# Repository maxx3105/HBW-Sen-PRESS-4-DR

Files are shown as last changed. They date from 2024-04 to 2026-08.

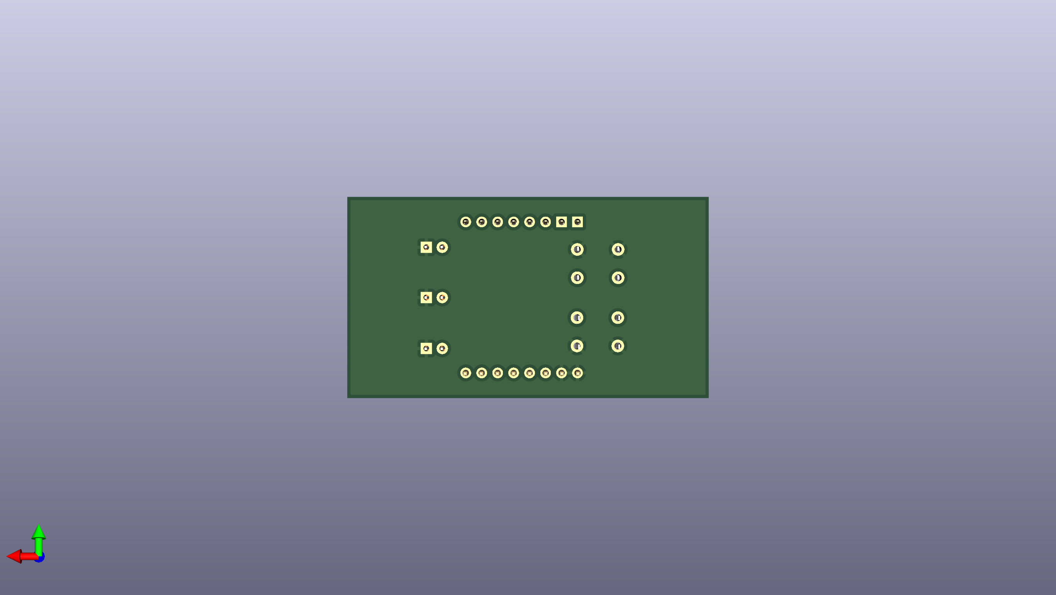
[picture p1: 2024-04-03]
HBW-Sen-PRESS-4_Platine2/Pictures/HBW-Sen-PRESS-4_Platine2_BOTTOM.png

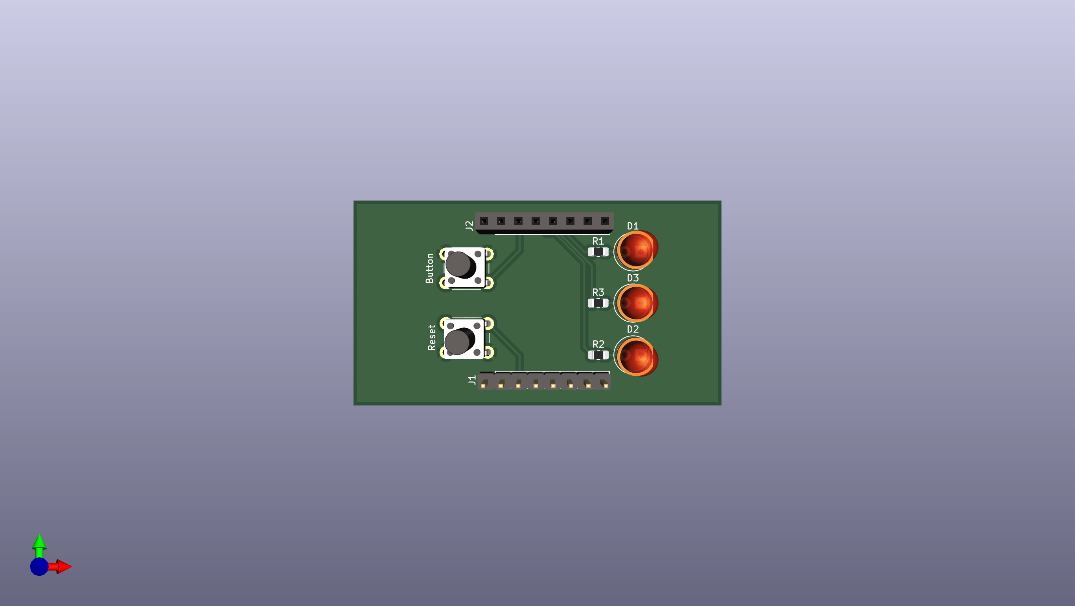
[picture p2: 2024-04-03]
HBW-Sen-PRESS-4_Platine2/Pictures/HBW-Sen-PRESS-4_Platine2_TOP.png

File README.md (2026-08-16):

# HBW-Sen-PRESS-4-DR

HomeMatic-Wired-Drucksensormodul für Hutschienenmontage

## Überblick

HomeMatic-Wired-Gerät (RS485) zur Überwachung hydraulischer Drücke mit
Industrie-Drucksensoren. Es stellt 4 analoge Sensoreingänge bereit (A0–A3).
Nicht belegte Kanäle werden in der CCU über `Sensortyp = NICHT_BELEGT` abgeschaltet.

### Basiert auf:
- **HBWired** von Thorsten Pferdekaemper: https://github.com/ThorstenPferdekaemper/HBWired
- **HB-UNI-Sen-PRESS** von jp112sdl: https://github.com/jp112sdl/HB-UNI-Sen-PRESS

## Aufbau des Repositories

```
HBW-Sen-PRESS-4-DR/
├── HBW-Sen-PRESS-4-DR/            Arduino-Sketch (Ordnername muss zur .ino passen)
│   ├── HBW-Sen-PRESS-4-DR.ino
│   ├── HBW-Sen-PRESS-4-DR_config_example.h   Pins, EepromPtr, USE_HARDWARE_SERIAL
│   ├── HBWAnalogPRESS.h
│   └── HBWAnalogPRESS.cpp
├── hbw-sen-press-4-dr.xml         CCU-Gerätedefinition (hs485types)
├── HBW-Sen-PRESS-4_Platine1/    KiCad-Projekt Hauptplatine (+ Gerber)
├── HBW-Sen-PRESS-4_Platine2/    KiCad-Projekt zweite Platine (+ Gerber)
├── BUGFIXES.md                  was in v0.01–v0.03 defekt war und warum
└── CLAUDE.md                    kompakter Projektstand / Übergabenotizen
```

## Hardware

### Unterstützte Sensoren
- **0,5 MPa** Hydraulik-Drucksensor (0–5 bar / 0–72,5 PSI)
- **1,2 MPa** Hydraulik-Drucksensor (0–12 bar / 0–174 PSI)

Beide liefern ein Analogsignal von **0,5 V bis 4,5 V**:
- 0,5 V = 0 bar
- 4,5 V = Endwert (5 bzw. 12 bar je nach Sensortyp)

### Bauteile
- **ATmega328P** Mikrocontroller (alternativ Arduino Nano)
- **MAX487E** RS485-Transceiver
- **MC34063AD** Step-Down-Wandler (24 V Bus → 5 V)
- Analogeingänge: A0–A3 in Verwendung

### Merkmale der Platine
- Hutschienenmontage
- Identify-LED zum Auffinden im Verteiler (blinkt, solange `IDENTIFY_LED` in
  den Geräteparametern gesetzt ist)
- RS485-Busanschluss (A, B, GND, +24 V)
- Schraubklemmen für die Sensoren
- ISP-Programmierstecker
- Status-LED
- Taster für Werksreset

## Pinbelegung

| Pin | Funktion |
|-----|---|
| A0–A3 | Analogeingänge der Drucksensoren |
| D3 | RS485 TXEN |
| A6 | Taster für Werksreset |
| D12 | Identify-LED (optional, auskommentieren wenn nicht bestückt) |
| D13 | Status-LED |

Pins, `EepromPtr` und `USE_HARDWARE_SERIAL` stehen in
`HBW-Sen-PRESS-4-DR_config_example.h`. Bei abweichender Hardware die Datei
kopieren und die Kopie im Sketch einbinden — dann überschreibt sie eine neue
Version aus GitHub nicht.

## Funktionsumfang

### Konfiguration je Kanal (in CCU/FHEM)

| Parameter | Bereich | Vorgabe | Bedeutung |
|---|---|---|---|
| **Sensortyp** | 0.5MPa / 1.2MPa / NICHT_BELEGT | NICHT_BELEGT | Sensortyp wählen oder Kanal abschalten |
| **SEND_DELTA_VALUE** | 0,0–2,54 bar | 0,1 bar | Sendet, sobald sich der Druck um diesen Betrag ändert |
| **OFFSET** | −1,27 bis +1,27 bar | 0,0 bar | Kalibrier-Offset (vorzeichenbehaftet, mit Bias 127 gespeichert) |
| **UPDATE_INTERVAL** | 1–254 s | 30 s | Pause zwischen zwei Messreihen |
| **SEND_MIN_INTERVAL** | 10–3600 s | 30 s | Mindestabstand zwischen zwei Sendungen |
| **SEND_MAX_INTERVAL** | 10–3600 s | 600 s | Spätestens nach dieser Zeit wird gesendet |

Die Obergrenzen vermeiden den Wert aus lauter Einsen (`0xFF` / `0xFFFF`) — der
markiert eine gelöschte EEPROM-Zelle und wird stattdessen auf die Vorgabe
abgebildet.

### Ablauf

1. **Messung**: alle SAMPLE_INTERVAL (3 s) ein ADC-Wert, gemittelt über
   MAX_SAMPLES (4) — ohne blockierendes `delay()`, damit der RS485-Empfang
   reaktionsfähig bleibt. Nach einer vollständigen Messreihe pausiert der Kanal
   für UPDATE_INTERVAL.
2. **Umrechnung**: ADC → Spannung → Druck (abhängig vom Sensortyp)
3. **Kalibrierung**: OFFSET anwenden
4. **Sendeentscheidung** (in jedem Schleifendurchlauf geprüft, unabhängig vom
   Messzyklus):
   - Mindestens SEND_MIN_INTERVAL seit der letzten Sendung abwarten
   - Senden, wenn sich der Druck um ≥ SEND_DELTA_VALUE geändert hat
   - Nach SEND_MAX_INTERVAL in jedem Fall senden
   - Bei `BUS_BUSY` bleibt der Messwert offen, statt als gesendet zu gelten

Ein vollständiger Messwert entsteht damit alle
`(MAX_SAMPLES − 1) × SAMPLE_INTERVAL + UPDATE_INTERVAL` Sekunden, mit den
Vorgabewerten also alle 39 s. `UPDATE_INTERVAL` ist die Pause *zwischen* den
Messreihen, nicht die Messrate — auf 1 s gestellt misst das Gerät alle 10 s.

## Installation

### 1. Arduino-IDE vorbereiten
```bash
git clone https://github.com/ThorstenPferdekaemper/HBWired
# nach Arduino/libraries/HBWired kopieren
```

### 2. Übersetzen und flashen

Der Sketch liegt im Unterordner `HBW-Sen-PRESS-4-DR/` (der Ordnername muss dem
`.ino`-Namen entsprechen).

- `HBW-Sen-PRESS-4-DR/HBW-Sen-PRESS-4-DR.ino` in der Arduino-IDE öffnen
- Board: **Arduino Nano** (ATmega328P)
- Betriebsart im Konfig-Header wählen: `USE_HARDWARE_SERIAL` gesetzt =
  Produktivbetrieb (RS485 über die Hardware-UART, keine Debug-Ausgabe),
  auskommentiert = Debug über USB und RS485 über SoftwareSerial
- Flashen über ISP oder Bootloader

Oder aus dem Projektverzeichnis heraus:

```
arduino-cli compile --fqbn arduino:avr:nano:cpu=atmega328 HBW-Sen-PRESS-4-DR
arduino-cli compile --fqbn arduino:avr:nano:cpu=atmega328 --upload --programmer usbasp HBW-Sen-PRESS-4-DR
```

Hinweis: Ist die EESAVE-Fuse nicht gesetzt, löscht jeder ISP-Flash das EEPROM —
und damit die Busadresse.

### 3. CCU/RaspberryMatic einrichten
1. `hbw-sen-press-4-dr.xml` auf die CCU kopieren
2. Gerätedefinition einbinden (Addon bzw. FHEM)
3. Gerät an den RS485-Bus anschließen
4. Anlernen und aus dem Posteingang übernehmen

## EEPROM-Belegung

`HBWDevice` liest die Konfigurationsstruktur ab EEPROM-Adresse `0x01`
(siehe `readConfig()` in HBWired.cpp), Struktur-Offset 6 landet also auf `0x07`.

```
0x00      : Gerätetyp (0x50)
0x01      : Logging-Zeit
0x02-0x05 : Zentralen-Adresse
0x06      : Bit 0 Direct-Link-Flag, Bit 1 Identify-LED (invertiert: 1 = aus)
0x07      : Kanal 1, Konfiguration (8 Byte)
  +0: send_delta_value
  +1: offset (Bias 127: 0 = −1,27 bar, 127 = 0,00 bar, 254 = +1,27 bar)
  +2-3: send_max_interval (16 Bit, little endian)
  +4-5: send_min_interval (16 Bit, little endian)
  +6: update_interval
  +7: pressure_sensor_type
0x0F/0x17/0x1F : Kanal 2..4, Konfiguration
0x3FC-0x3FF : OWN_ADDRESS (Busadresse, E2END−3 beim 1-kB-EEPROM des 328P)
```

Die Belegung ist über drei `static_assert` in
`HBW-Sen-PRESS-4-DR/HBW-Sen-PRESS-4-DR.ino` an die XML gekoppelt — Strukturgröße,
Startoffset der Kanäle und der Abstand zu `OWN_ADDRESS` müssen passen,
sonst bricht der Build.

## Fehlersuche

### Keine Messwerte / alles null
- Verdrahtung prüfen (3-adrig: VCC, GND, Signal)
- Liefert der Sensor tatsächlich 0,5–4,5 V?
- Ist der Kanal freigegeben (`Sensortyp` ≠ `NICHT_BELEGT`)? Bei abgeschaltetem
  Kanal wird weder gemessen noch gesendet.

### Falsche Druckwerte
- Richtigen Sensortyp gewählt (0,5 MPa vs. 1,2 MPa)?
- Zur Kalibrierung den Parameter OFFSET verwenden
- VCC muss *nicht* exakt 5,0 V betragen: Die Sensoren arbeiten ratiometrisch,
  ihr Ausgang skaliert mit der Versorgung. Hängen Sensor und ADC an derselben
  5-V-Schiene, hebt sich die Abweichung des Reglers auf — deshalb wird die
  VCC-Referenz des ADC benutzt und nicht die interne 1,1-V-Referenz.
  Wichtig ist nur, dass Sensor und MCU aus **derselben** Schiene versorgt werden.

### Gerät kommuniziert nicht
- RS485-Verdrahtung prüfen (A/B nicht vertauscht)
- TX/RX-Aktivität beobachten

## Lizenz

Creative Commons BY-NC-SA 3.0 AT
http://creativecommons.org/licenses/by-nc-sa/3.0/at/

## Dank an

- Thorsten Pferdekaemper – HBWired-Framework
- Dirk Hoffmann – Beiträge zu HBWired
- jp112sdl – ursprüngliches Konzept HB-UNI-Sen-PRESS

## Änderungsverlauf

### v0.05
- Gerät in HBW-Sen-PRESS-4-DR umbenannt (Typ-Byte bleibt 0x50; wegen des
  Namenswechsels in der CCU löschen und neu anlernen)
- Pinbelegung, `EepromPtr` und `USE_HARDWARE_SERIAL` in einen Konfig-Header
  ausgelagert
- Identify-LED ergänzt

### v0.04
- Kanalzahl auf 4 festgelegt (A0–A3)

### v0.01 (02.04.2024)
- Erste Fassung auf Basis von HB-UNI-Sen-PRESS
- CCU-Anbindung über XML

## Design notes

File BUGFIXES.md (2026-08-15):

# Bug Fixes und Verbesserungen - HBW-Sen-PRESS-4-DR

## v0.03 → v0.04: Kanalzahl 4, count_from_sysinfo endgültig ausgeschlossen

Das CRMB2-Gehäuse führt nur 4 Sensoranschlüsse heraus, also `NUMBER_OF_CHAN 4`
und `count="4"`. Zuvor wurde geprüft, ob sich die Kanalzahl dynamisch über
`count_from_sysinfo` melden lässt (eine XML/Firmware für 4 und 8 Kanäle).

**Ergebnis: geht nicht.** Belegt auf zwei Wegen:

1. **Binär**, auf der OpenCCU:
```
strings $(which rfd)     | grep -i "count_from\|sysinfo"
   -> SYSINFO, SYSINFO_SWVER, SYSINFO_TYPE, SYSINFO_SERIAL, SYSINFO_CODE,
      SYSINFO_CH_A, SYSINFO_CH_B, count_from_sysinfo, peering_sysinfo_expect_channel

strings $(which hs485d)  | grep -i "count_from\|count.*channel\|channel.*count"
   -> (keine Treffer)
```
`hs485d` kennt zwar `sysinfo` (gemeinsamer Matching-Code mit `rfd`, Meldung
`Matching "sysinfo" attribute … Trying "type" instead`), aber weder
`count_from_sysinfo` noch irgendeinen anders benannten Ersatz. Bei Funk sitzt
die Kanalzahl in der Pairing-Sysinfo (`SYSINFO_CH_A`/`_CH_B`, Byte 23) — das
Wired-Protokoll überträgt so etwas nicht.

2. **Am Bus:** Mit `count_from_sysinfo="23.0:0.4"` statt `count` erkennt die CCU
das Gerät weiterhin korrekt (Typenbezeichnung `HBW-Sen-PRESS`, Firmware 0.03,
Geräteparameter vorhanden), legt aber **null Kanäle** an → „Keine Parameter
einstellbar". Das unbekannte Attribut wird ignoriert, und ohne `count` gibt es
keine Kanäle.

Variable Kanalzahl geht bei Wired deshalb nur über getrennte Gerätetypen mit
eigenem Typ-Byte — so wie eq3 (`hmw_io_4_fm` 0x10 / `hmw_io_12_fm` 0x1B) und
wie im eigenen Bestand `hbw_lc_rgbww_3.xml` (0xD2) / `hbw_lc_rgbww_6.xml` (0xD1).

Merksatz für künftige Fälle: Ob ein CCU-Daemon ein XML-Attribut auswertet, klärt
`strings` auf das Binary — schneller und risikofreier als XML-Tausch am
laufenden System. Dass ein Attribut in keiner XML vorkommt, ist nur ein Indiz.

---

## Übersicht der Änderungen von v0.02 → v0.03

Gemeinsame Ursache der XML-Fehler: Die Datei wurde aus der Funk-XML von
HB-UNI-Sen-PRESS abgeleitet, nicht aus einer Wired-XML. HB (Funk/CC1101) und
HBW (Wired/RS485) haben unterschiedliche Frame-Layouts und Parameter-Interfaces.

Referenzen für den korrigierten Stand:
- `hs485types/hmw_sen_sc_12_dr.xml` (eq3-Original)
- `JP-HB-Devices-addon-fork/.../hs485types/hbw_1w_t10_v1.xml` (loetmeister,
  HBWired-Sensormodul mit analogen Messwerten — direkte Vorlage)
- `HBWired/src/HBWAnalogIn.cpp` (Lib-Referenz für Sampling und Sendelogik)

---

### 🔴 BLOCKER 1: Event-Frame in Funk-Syntax

**Problem:**
```xml
<frame id="PRESSURE_EVENT" direction="from_device" event="true"
       type="0x53" channel_field="11">
    <parameter type="integer" index="12.0" size="2.0" param="UNI_PRESSURE"/>
</frame>
```

`0x53` ist der MEASURE_EVENT-Typ eines AskSin-Funkgeräts. HBWired sendet aber:

```cpp
// HBWired.cpp, sendInfoMessage()
txFrame.data[0] = 0x69;         // 'i'
txFrame.data[1] = channel;      // Sensornummer
memcpy(&(txFrame.data[2]), data, length);
```

HMW-Frame-Layout: 4 Byte Ziel + 1 Byte Control + 4 Byte Absender = Index 0..8,
danach Kommando @9, Kanal @10, Payload ab @11.

**Auswirkung:** Die CCU ordnet die Info-Nachrichten keinem Datenpunkt zu. Der
Messwert wäre nie angekommen — auch bei fehlerfreiem Bus und Pairing.

**Fix:** ✅
```xml
<frame id="INFO_LEVEL" direction="from_device" event="true"
       type="#i" channel_field="10">
    <parameter type="integer" index="11.0" size="2.0" param="UNI_PRESSURE"/>
</frame>
```

---

### 🔴 BLOCKER 2: Sensortyp über `interface="config"`

**Problem:**
```xml
<physical type="integer" interface="config" list="1" index="+7.0" size="1"/>
```

`interface="config"` mit `list=` ist AskSin-Funk. HM485/hs485d kennt keine
Lists — der Parameter wird nie ins EEPROM geschrieben.

**Auswirkung:** `pressure_sensor_type` bleibt 0xFF → `afterReadConfig()` setzt
auf 0 → **jeder Kanal dauerhaft deaktiviert**, unabhängig von der CCU-Auswahl.

**Fix:** ✅
```xml
<physical size="1.0" type="integer" interface="eeprom">
    <address index="+7.0"/>
</physical>
```

---

### 🟠 BLOCKER 3: `count_from_sysinfo` existiert im Wired-Zweig nicht

**Problem:** `count_from_sysinfo="23.0:0.3"` kommt in keiner der 15 eq3- und
21 loetmeister-Wired-XMLs vor — nur in rftypes (Funk). Zusätzlich fassen die
3 Bit nur Werte 0..7, die angestrebten 8 Kanäle passen gar nicht hinein.

**Fix:** ✅ Festes `count="8"`. Damit entfallen das Kanalzahl-Byte an 0x17, die
`EEPROM.write(0x17, ...)` im Sketch und beide Padding-Blöcke; die Kanalconfigs
rücken von 0x23 auf 0x07 (direkt hinter den Device-Master-Block, wie in der
Referenz-XML).

---

### 🟠 Fehlend: LEVEL_GET und OWN_ADDRESS

- Ohne `<frame id="LEVEL_GET" direction="to_device" type="#S" channel_field="10"/>`
  und `<get request="LEVEL_GET" response="INFO_LEVEL"/>` kann die CCU den Wert
  nicht aktiv abfragen. HBWired beantwortet 'S' bereits (`HBWired.cpp`, `case 'S'`).
- `OWN_ADDRESS` fehlte komplett. Ergänzt an `0x03FC` — beim ATmega328P ist
  E2END = 0x3FF, die Busadresse liegt in den letzten 4 EEPROM-Bytes.
  Ohne diesen Block lässt sich die Busadresse nicht über die CCU setzen.

---

### 🔴 CODE: blockierendes `delay()` im ADC-Sampling

**Problem:** In v0.02 als „Verbesserung" eingeführt (siehe Punkt 8 weiter unten):
```cpp
for(uint8_t i = 0; i < 4; i++) {
    adcSum += analogRead(pin);
    delay(2);
}
```

**Auswirkung:** 8 ms blockierte `loop()` pro Messung und Kanal. Bei
SoftwareSerial-RS485 (Debug-Modus, ATmega328P hat nur einen UART) gehen in
dieser Zeit Empfangs-Frames verloren. `analogRead()` selbst braucht ~112 µs und
ist bereits die Wandlungspause — das `delay(2)` bringt keinen Rauschgewinn.

**Fix:** ✅ Inkrementelles Sampling wie `HBWAnalogIn`: ein Sample pro
`loop()`-Durchlauf, Mittelwert nach `MAX_SAMPLES`. Anders als in der Lib sind
`sum`/`sampleCount` **Member statt `static`** — in `HBWAnalogIn.cpp` sind sie
`static` in einer Member-Funktion und damit über alle Kanäle geteilt, was bei
mehreren Instanzen die Samples vermischt.

---

### 🟠 CODE: Sendeergebnis wurde ignoriert

**Problem:**
```cpp
device->sendInfoMessage(channel, 2, data);
lastSendValue = currentValue;   // auch wenn der Bus belegt war
```

**Auswirkung:** Bei `BUS_BUSY` gilt der Wert als gesendet. Die Delta-Prüfung
vergleicht danach gegen einen Wert, den die CCU nie gesehen hat — der Messwert
geht bis zum nächsten `send_max_interval` verloren.

**Fix:** ✅ Rückgabewert auswerten (wie `HBWAnalogIn.cpp`):
```cpp
if (device->sendInfoMessage(channel, sizeof(data), data) != HBWDevice::BUS_BUSY) {
    lastSendValue = currentValue;
}
lastSentTime = now;
```

---

### 🟡 CODE: Sendelogik hing am Messintervall

**Problem:** Die komplette Sendeprüfung lag innerhalb von
`if (now - lastActionTime >= nextActionDelay)`. `send_min_interval` und
`send_max_interval` konnten also nur zu Messzeitpunkten greifen.

**Fix:** ✅ Sendeblock aus dem Messblock herausgezogen, wird jetzt in jedem
`loop()`-Durchlauf ausgewertet.

---

### 🟡 CODE/XML: OFFSET kollidierte mit dem Leer-EEPROM-Marker

**Problem:** Offset signed in 1 Byte, dazu `if (config->offset != 0xFF)` als
„nicht gesetzt"-Prüfung. 0xFF ist als `int8_t` aber −1, also −0.01 bar — ein
gültiger Wert, der stumm verworfen wurde.

**Fix:** ✅ Bias 127 in der XML:
```xml
<conversion type="float_integer_scale" offset="1.27" factor="100"/>
```
`device = (param + 1.27) × 100` → −1.27 bar = 0, 0.00 bar = 127, +1.27 bar = 254.
0xFF liegt außerhalb des gültigen Bereichs und wird in `afterReadConfig()` auf
127 gesetzt. Aus demselben Grund enden `SEND_DELTA_VALUE` bei 2.54 statt 2.55
und `UPDATE_INTERVAL` bei 254 statt 255.

---

### ✅ Neu: EEPROM-Layout zur Compile-Zeit geprüft

Der `address_step`-Fehler aus v0.01 kann nicht mehr unbemerkt auftreten:

```cpp
static_assert(sizeof(hbw_config_analog_press) == 8, ...);
static_assert(offsetof(hbw_config, analogPressConfigs) == 6, ...);   // -> EEPROM 0x07
static_assert(0x01 + sizeof(hbw_config) <= 0x03FC, ...);             // OWN_ADDRESS
```

Build-Stand (arduino:avr:nano, ATmega328P):

| Variante | Flash | RAM |
|---|---|---|
| Debug (SoftwareSerial + USB-Debug) | 12878 B (41%) | 493 B (24%) |
| Produktiv (`USE_HARDWARE_SERIAL`) | 11200 B (36%) | 378 B (18%) |

---

## Übersicht der Änderungen von v0.01 → v0.02

### 🐛 KRITISCHE BUGFIXES

#### 1. **Doppelte Channel-Initialisierung** (Memory Leak)
**Problem:**
```cpp
// In Test_A.ino v0.01:
for (uint8_t i = 0; i < NUMBER_OF_CHAN; i++) {
    channels[i] = new HBWAnalogPRESS(...);  // Zeile 80-82
}
// ... später im Code ...
for (uint8_t i = 0; i < NUMBER_OF_CHAN; i++) {
    channels[i] = new HBWAnalogPRESS(...);  // Zeile 136-138 - NOCHMAL!
}
```

**Auswirkung:** 
- Pointer wurde überschrieben
- Alter Speicher nicht freigegeben → Memory Leak
- Bei jedem Reset wächst der RAM-Verlust

**Fix:** Zweite Initialisierungsschleife entfernt ✅

---

#### 2. **EEPROM Address Mapping - Falsche Schrittweite**
**Problem:**
```xml
<!-- v0.01 XML: -->
<paramset type="MASTER" address_start="0x23" address_step="6">
```

Aber die Struktur ist 8 Bytes groß:
```cpp
struct hbw_config_analog_press {
  uint8_t  send_delta_value;     // +0
  uint8_t  offset;               // +1
  uint16_t send_max_interval;    // +2-3
  uint16_t send_min_interval;    // +4-5
  uint8_t  update_interval;      // +6
  uint8_t  pressure_sensor_type; // +7
}; // = 8 Bytes!
```

**Auswirkung:**
- Kanal 1: 0x23-0x2A ✓
- Kanal 2: 0x29-0x30 ✗ (Überschneidung mit Kanal 1!)
- Kanal 3: 0x2F-0x36 ✗ (Chaos)
- Parameter wurden überschrieben
- Konfiguration funktionierte nicht korrekt

**Fix:** `address_step="8"` ✅

**Neue Speicherkarte:**
```
Kanal 1: 0x23-0x2A  (8 Bytes)
Kanal 2: 0x2B-0x32  (8 Bytes)
Kanal 3: 0x33-0x3A  (8 Bytes)
Kanal 4: 0x3B-0x42  (8 Bytes)
```

---

#### 3. **SEND_MIN_INTERVAL - Timing Bug**
**Problem:**
```cpp
// v0.01 Code:
if (config->send_min_interval != 0xFFFF) {
    if ((now - lastSentTime) < ((uint32_t)config->send_min_interval * 1000)) {
        return; // Springt aus der GANZEN Funktion!
    }
}
```

**Auswirkung:**
- `lastActionTime` wird NICHT gesetzt
- `nextActionDelay` wird NICHT aktualisiert
- Die nächste Messung findet SOFORT statt (nicht nach UPDATE_INTERVAL)
- CPU-Last steigt, ADC wird permanent gelesen

**Fix:**
```cpp
// v0.02 Code:
if (config->send_min_interval != 0xFFFF && config->send_min_interval != 0) {
    if ((now - lastSentTime) < ((uint32_t)config->send_min_interval * 1000)) {
        // Messung wurde aktualisiert, aber zu früh zum Senden
        return; // Timing wurde VORHER korrekt gesetzt
    }
}
```

Timing-Updates wurden VOR dem MIN_INTERVAL Check verschoben ✅

---

#### 4. **SEND_MIN_INTERVAL - Datentyp-Konflikt**
**Problem:**
```cpp
// C-Struktur sagt:
uint16_t send_min_interval;  // 2 Bytes

// XML v0.01 sagt:
<parameter id="SEND_MIN_INTERVAL">
    <physical size="1.0" type="integer" ...>  // Nur 1 Byte!
```

**Auswirkung:**
- High-Byte des Wertes wurde in `update_interval` geschrieben
- Werte >255 funktionierten nicht
- Max. MIN_INTERVAL war 255s statt 65535s

**Fix:** XML jetzt auch 2 Bytes ✅
```xml
<physical size="2.0" type="integer" interface="eeprom" endian="little">
    <address index="+4.0"/>
</physical>
```

---

#### 5. **Sensortyp-Index - Absolut statt Relativ**
**Problem:**
```xml
<!-- v0.01: -->
<parameter id="Sensortyp">
    <physical type="integer" interface="config" list="1" index="39.0" size="1"/>
</parameter>
```

**Auswirkung:**
- Fest kodierte Adresse 0x39
- Funktioniert nur für Kanal 1 zufällig korrekt
- Bei anderen Kanälen: falsches EEPROM-Byte

**Fix:** Relative Adressierung ✅
```xml
<physical type="integer" interface="config" list="1" index="+7.0" size="1"/>
```

---

### ⚙️ FEHLENDE FEATURES IMPLEMENTIERT

#### 6. **OFFSET-Parameter nicht verwendet**
**Problem:**
- Variable `offset` existierte in struct
- Parameter war in XML (v0.01 falsch platziert)
- Code verwendete Offset NIEMALS

**Auswirkung:**
- Sensor-Kalibrierung unmöglich
- Ungenaue Messungen konnten nicht korrigiert werden

**Fix:** Offset-Anwendung implementiert ✅
```cpp
if (config->offset != 0xFF && config->offset != 0) {
    int16_t offsetValue = (int8_t)config->offset; // Signed!
    int32_t temp = (int32_t)currentValue + offsetValue;
    
    // Clamp to valid range
    if (temp < 0) currentValue = 0;
    else if (temp > 65535) currentValue = 65535;
    else currentValue = (uint16_t)temp;
}
```

---

#### 7. **OFFSET im falschen Paramset**
**Problem:**
```xml
<!-- v0.01: OFFSET war im Device-Master -->
<paramset id="HBW-Sen-PRESS_dev_master" type="MASTER">
    <parameter id="OFFSET">
        <address index="+1.0"/>  <!-- Bezieht sich auf 0x0001! -->
    </parameter>
</paramset>
```

**Auswirkung:**
- Offset galt für ALLE Kanäle gleichzeitig
- Konnte nicht pro Kanal kalibriert werden
- Überschrieb LOGGING_TIME Parameter

**Fix:** OFFSET in Channel-Paramset verschoben ✅
```xml
<paramset type="MASTER" id="hbw_press_master" address_start="0x23" address_step="8">
    <parameter id="OFFSET">
        <address index="+1.0"/>  <!-- Jetzt relativ zu Kanal-Start -->
    </parameter>
</paramset>
```

---

### 🔧 VERBESSERUNGEN

#### 8. **ADC Oversampling verbessert** ⚠️ in v0.03 zurückgenommen
> Das eingefügte `delay(2)` war keine Verbesserung, sondern ein Bug: es
> blockiert die `loop()` und kostet auf SoftwareSerial-RS485 Empfangs-Frames.
> Siehe v0.03-Abschnitt oben.

**Vorher:**
```cpp
for(uint8_t i=0; i<4; i++) { 
    adcSum += analogRead(pin); 
}
```

**Nachher:**
```cpp
for(uint8_t i = 0; i < 4; i++) { 
    adcSum += analogRead(pin);
    delay(2); // Kleine Pause zwischen Samples
}
```

**Vorteil:** Bessere Rauschunterdrückung

---

#### 9. **Firmware-Version erhöht**
```cpp
// v0.01:
#define FIRMWARE_VERSION 0x0001

// v0.02:
#define FIRMWARE_VERSION 0x0002
```

---

#### 10. **Debug-Output verbessert**
**Neu:**
- Freier RAM angezeigt
- Alle ADC-Kanäle mit Spannungswerten
- Firmware-Version im Startup-Banner
- Strukturierte Debug-Ausgabe

---

#### 11. **Kommentare und Dokumentation**
- Vollständige README.md
- Inline-Kommentare in allen Dateien
- EEPROM Memory Map dokumentiert
- Troubleshooting-Guide

---

## Zusammenfassung der kritischen Fixes

| Bug | Schwere | Status |
|-----|---|---|
| Doppelte Initialisierung | 🔴 Kritisch | ✅ Gefixt |
| EEPROM address_step | 🔴 Kritisch | ✅ Gefixt |
| MIN_INTERVAL Timing | 🔴 Kritisch | ✅ Gefixt |
| MIN_INTERVAL Datentyp | 🟠 Hoch | ✅ Gefixt |
| Sensortyp-Index | 🟠 Hoch | ✅ Gefixt |
| OFFSET nicht verwendet | 🟡 Mittel | ✅ Gefixt |
| OFFSET falsch platziert | 🟡 Mittel | ✅ Gefixt |

---

## Test-Empfehlungen nach Bugfixes

### 1. EEPROM Test
```cpp
// Lese Konfiguration aller Kanäle aus
// Prüfe ob Werte an richtigen Adressen stehen
```

### 2. Timing Test
```cpp
// Setze UPDATE_INTERVAL = 10s
// Setze MIN_INTERVAL = 30s
// → Messung alle 10s, Senden max. alle 30s
```

### 3. Offset Test
```cpp
// Setze bekannten Druck (z.B. 2.00 bar)
// Zeigt 1.95 bar → OFFSET = +0.05 bar
// Prüfe ob Anzeige korrigiert wird
```

### 4. Memory Leak Test
```cpp
// Mehrfach Reset drücken
// Free RAM sollte GLEICH bleiben
```

---

## Dateien zum Deployment

✅ `HBWAnalogPRESS.h` - Header mit korrekten Kommentaren
✅ `HBWAnalogPRESS.cpp` - Alle Bugfixes implementiert
✅ `HBW-Sen-PRESS-4-DR.ino` - Sauberer Setup, keine doppelte Init
✅ `HBW-Sen-PRESS.xml` - Korrigiertes Address-Mapping
✅ `README.md` - Vollständige Dokumentation
✅ `BUGFIXES.md` - Diese Datei

Bereit für Produktion! 🚀

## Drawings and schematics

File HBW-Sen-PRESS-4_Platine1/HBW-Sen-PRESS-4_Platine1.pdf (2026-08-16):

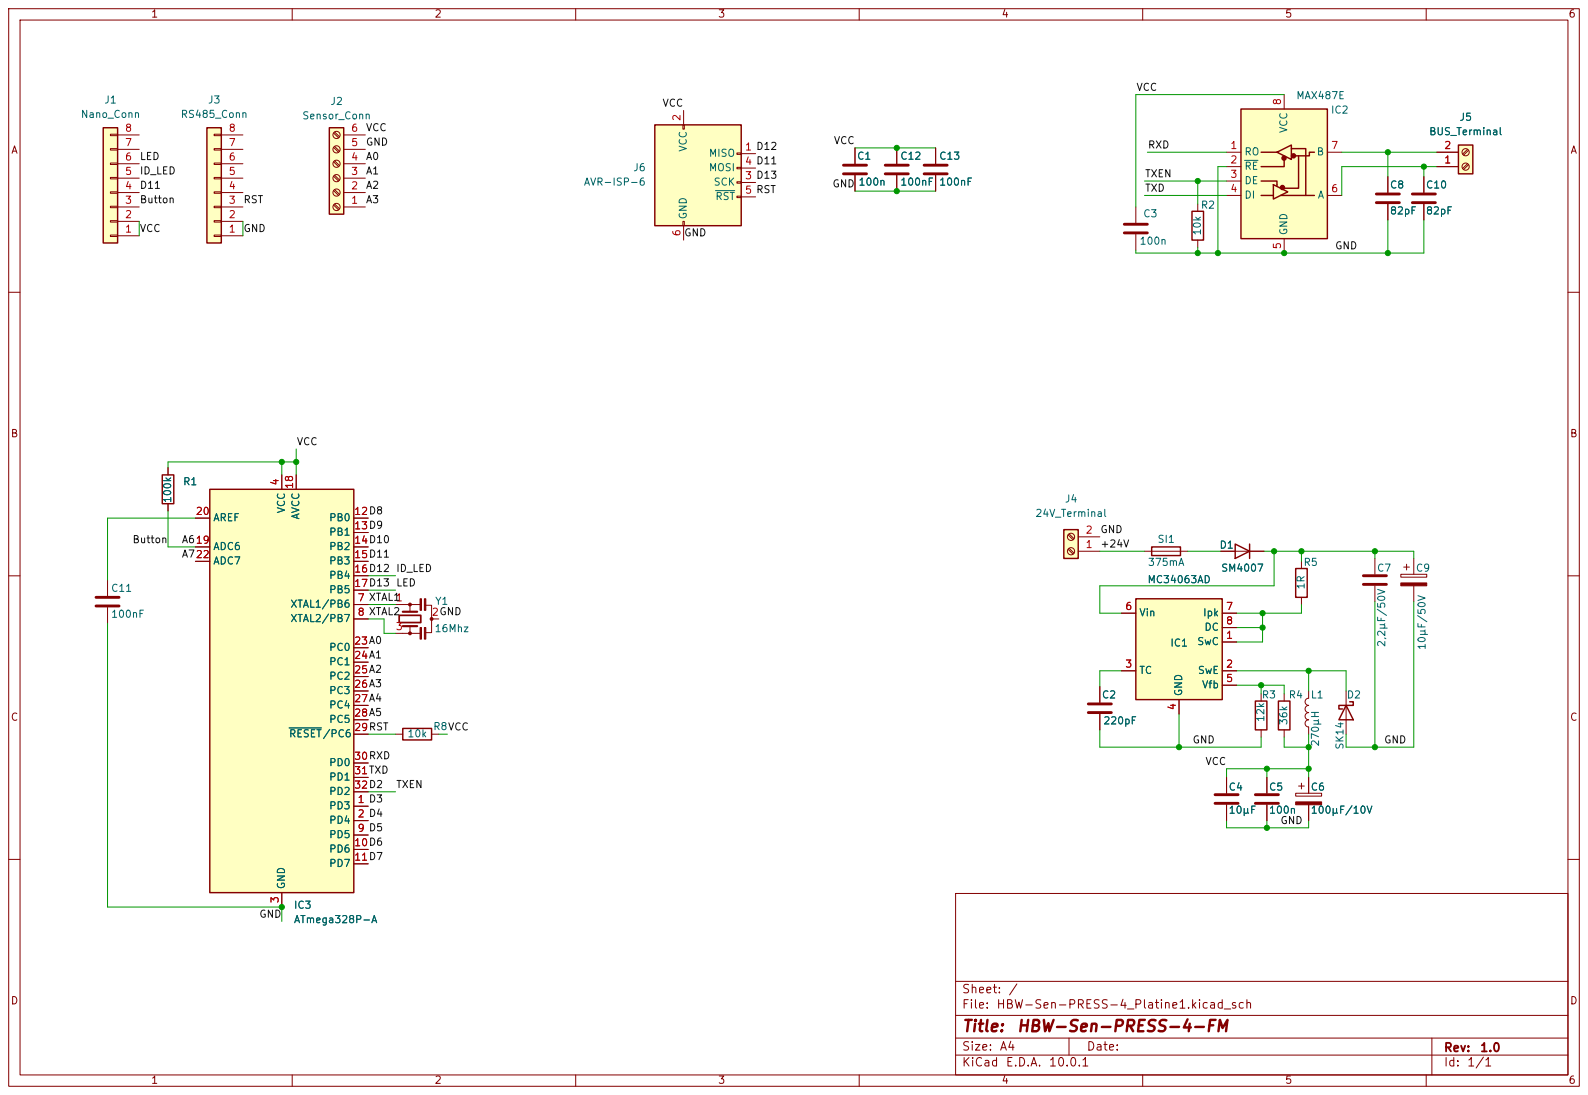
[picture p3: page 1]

Sheet: /
File: HBW-Sen-PRESS-4_Platine1.kicad_sch
Title: HBW-Sen-PRESS-4-FM

Size: A4 | Rev: 1.0
KiCad E.D.A. 10.0.1 | Id: 1/1

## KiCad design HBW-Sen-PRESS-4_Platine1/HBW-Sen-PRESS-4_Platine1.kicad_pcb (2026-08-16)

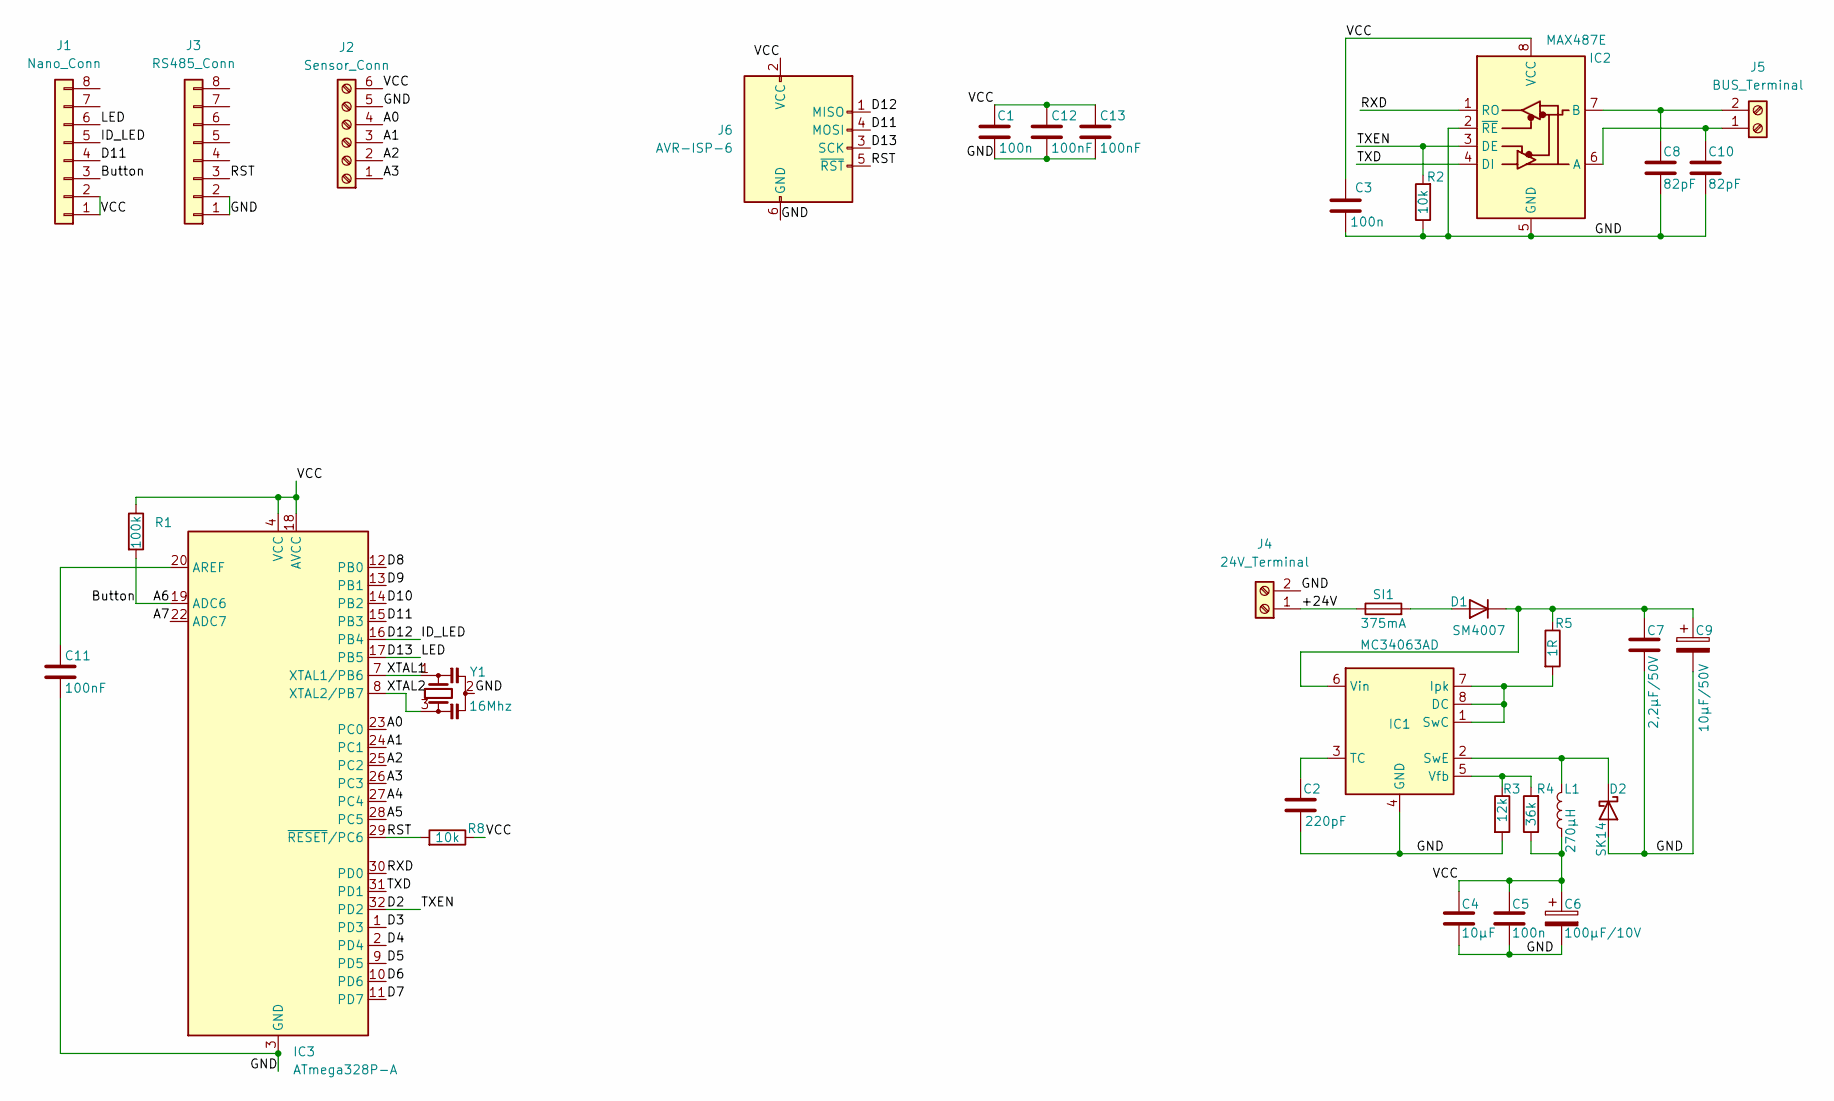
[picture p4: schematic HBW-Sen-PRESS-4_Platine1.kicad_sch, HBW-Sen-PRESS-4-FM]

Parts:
C1, C3, C5: 100n; C_0805_2012Metric_Pad1.18x1.45mm_HandSolder
C2: 220pF; C_0805_2012Metric_Pad1.18x1.45mm_HandSolder
C4: 10µF; C_1210_3225Metric_Pad1.33x2.70mm_HandSolder
C6: 100µF/10V; CP_Radial_D5.0mm_P2.50mm
C7: 2,2µF/50V; C_1210_3225Metric_Pad1.33x2.70mm_HandSolder
C8, C10: 82pF; C_0805_2012Metric_Pad1.18x1.45mm_HandSolder
C9: 10µF/50V; CP_Radial_D5.0mm_P2.50mm
C11, C12, C13: 100nF; C_0805_2012Metric_Pad1.18x1.45mm_HandSolder
D1: SM4007; D_MELF
D2: SK14; D_SMA_Handsoldering
IC1: MC34063AD; SOIC-8_3.9x4.9mm_P1.27mm
IC2: MAX487E; SOIC-8_3.9x4.9mm_P1.27mm
IC3: ATmega328P-A; TQFP-32_7x7mm_P0.8mm
J1: Nano_Conn; PinHeader_1x08_P2.54mm_Vertical
J2: Sensor_Conn; TerminalBlock_CUI_TB007-508-06_1x06_P5.08mm_Horizontal
J3: RS485_Conn; PinHeader_1x08_P2.54mm_Vertical
J4: 24V_Terminal; TerminalBlock_bornier-2_P5.08mm
J5: BUS_Terminal; TerminalBlock_bornier-2_P5.08mm
J6: AVR-ISP-6; PinHeader_2x03_P2.54mm_ISP
L1: 270µH; L_Taiyo-Yuden_MD-4040
R1: 100k; R_0805_2012Metric_Pad1.20x1.40mm_HandSolder
R2, R8: 10k; R_0805_2012Metric_Pad1.20x1.40mm_HandSolder
R3: 12k; R_0805_2012Metric_Pad1.20x1.40mm_HandSolder
R4: 36k; R_0805_2012Metric_Pad1.20x1.40mm_HandSolder
R5: 1R; R_0805_2012Metric_Pad1.20x1.40mm_HandSolder
SI1: 375mA; FUSC6127X294N
Y1: 16Mhz; Resonator_SMD_Murata_CSTxExxV-3Pin_3.0x1.1mm_HandSoldering

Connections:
/+24V: J4.1, SI1.1
/A0: IC3.23 (PC0), J2.4
/A1: IC3.24 (PC1), J2.3
/A2: IC3.25 (PC2), J2.2
/A3: IC3.26 (PC3), J2.1
/A4: IC3.27 (PC4)
/A5: IC3.28 (PC5)
/A6: IC3.19 (ADC6), J1.3, R1.2
/A7: IC3.22 (ADC7)
/D2: IC2.3 (DE), IC3.32 (PD2), R2.2
/D3: IC3.1 (PD3)
/D4: IC3.2 (PD4)
/D5: IC3.9 (PD5)
/D6: IC3.10 (PD6)
/D7: IC3.11 (PD7)
/D8: IC3.12 (PB0)
/D9: IC3.13 (PB1)
/D10: IC3.14 (PB2)
/D11: IC3.15 (PB3), J1.4, J6.4 (MOSI)
/D12: IC3.16 (PB4), J1.5, J6.1 (MISO)
/D13: IC3.17 (PB5), J1.6, J6.3 (SCK)
/GND: C1.2, C2.2, C3.1, C4.2, C5.1, C6.2, C7.2, C8.2, C9.2, C10.2, C11.1, C12.1, C13.1, D2.2 (A), IC1.4 (GND), IC2.2 (~RE), IC2.5 (GND), IC3.3 (GND), IC3.5 (GND), IC3.21 (GND), J2.5, J3.1, J3.2, J4.2, J6.6 (GND), R2.1, R3.2, Y1.2
/RST: IC3.29 (~RESET/PC6), J3.3, J6.5 (~RST), R8.2
/RXD: IC2.1 (RO), IC3.30 (PD0)
/TXD: IC2.4 (DI), IC3.31 (PD1)
/VCC: C1.1, C3.2, C4.1, C5.2, C6.1, C12.2, C13.2, IC2.8 (VCC), IC3.4 (VCC), IC3.6 (VCC), IC3.18 (AVCC), J1.1, J1.2, J2.6, J6.2 (VCC), L1.1, R1.1, R4.1, R8.1
/XTAL1: IC3.7 (XTAL1/PB6), Y1.1
/XTAL2: IC3.8 (XTAL2/PB7), Y1.3
unnamed: D1.2 (A), SI1.2
unnamed: C7.1, C9.1, D1.1 (K), IC1.6 (Vin), R5.1
unnamed: D2.1 (K), IC1.2 (SwE), L1.2
unnamed: IC1.1 (SwC), IC1.7 (Ipk), IC1.8 (DC), R5.2
unnamed: C2.1, IC1.3 (TC)
unnamed: IC1.5 (Vfb), R3.1, R4.2
unnamed: C10.1, IC2.6 (A), J5.1
unnamed: C8.1, IC2.7 (B), J5.2
unnamed: C11.2, IC3.20 (AREF)

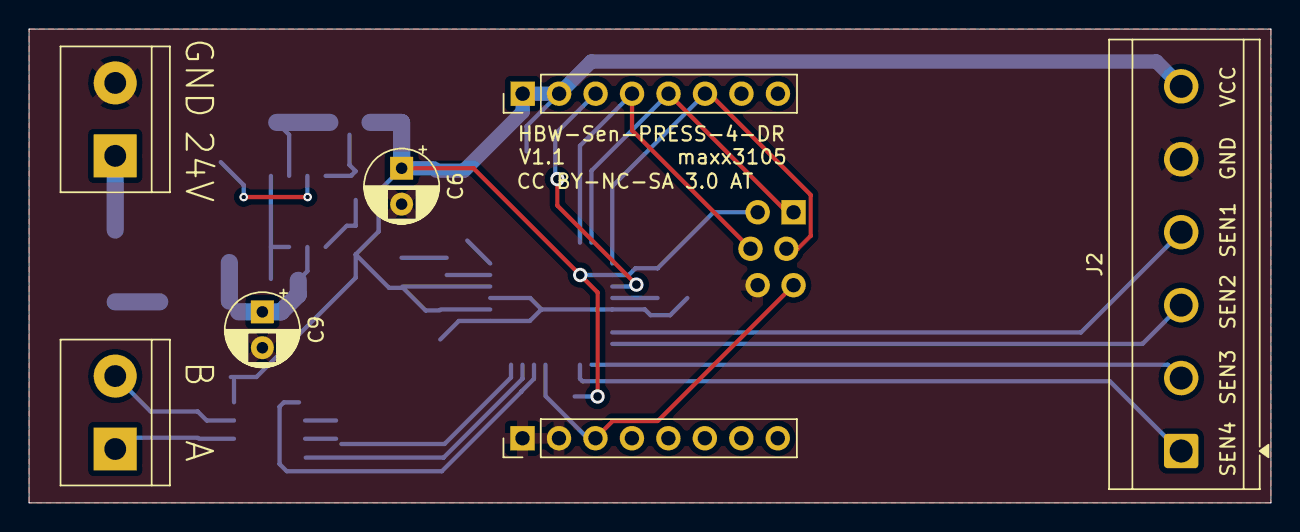
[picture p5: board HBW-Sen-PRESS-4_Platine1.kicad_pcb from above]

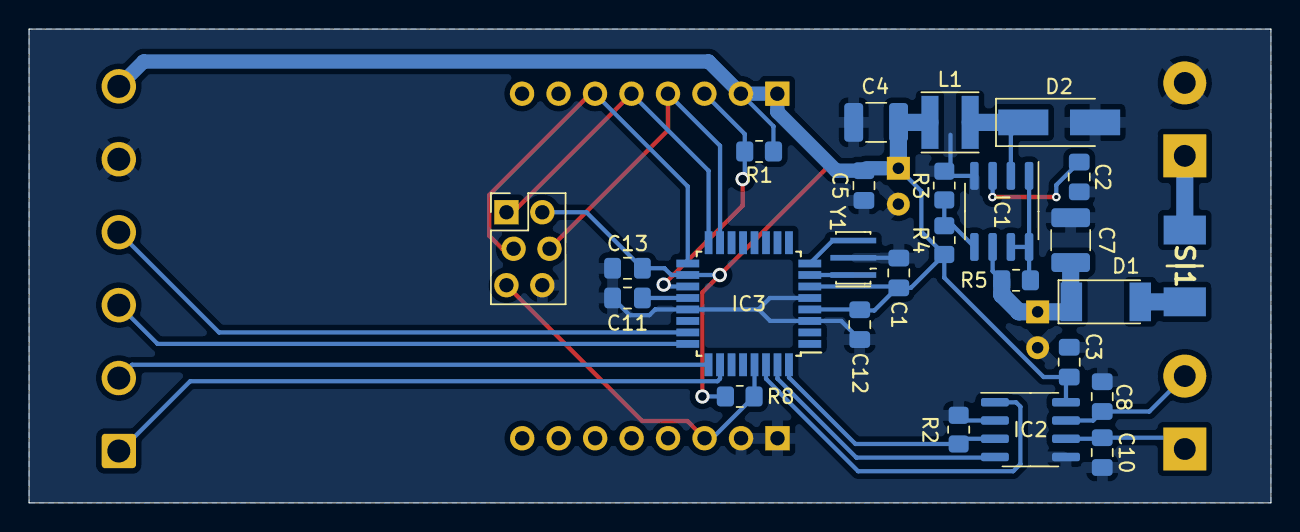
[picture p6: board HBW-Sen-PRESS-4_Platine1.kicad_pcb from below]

Board: 2 copper layers, 86.5 x 33.0 mm, 33 parts (26 on the bottom side), 26 nets.

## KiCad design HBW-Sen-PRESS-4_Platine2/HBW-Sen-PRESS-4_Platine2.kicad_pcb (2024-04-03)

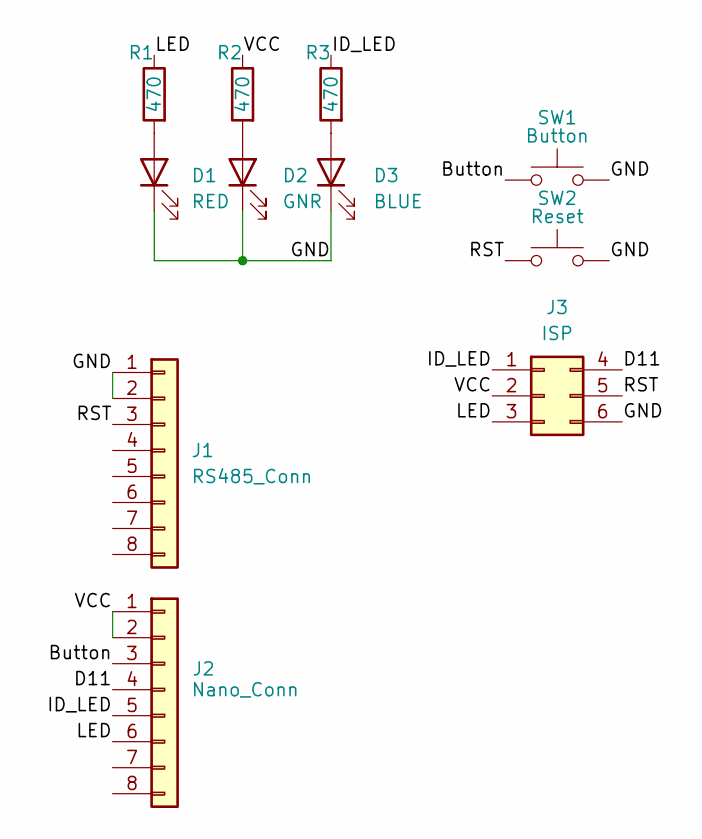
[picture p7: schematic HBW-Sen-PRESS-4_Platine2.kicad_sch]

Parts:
D1: RED; LED_D5.0mm
D2: GNR; LED_D5.0mm
D3: BLUE; LED_D5.0mm
J1: RS485_Conn; PinHeader_1x08_P2.54mm_Vertical
J2: Nano_Conn; PinSocket_1x08_P2.54mm_Vertical
J3: ISP; PinHeader_2x03_P2.54mm_Vertical
R1, R2, R3: 470; R_0805_2012Metric_Pad1.20x1.40mm_HandSolder
SW1: Button; SW_PUSH_6mm_H13mm
SW2: Reset; SW_PUSH_6mm_H13mm

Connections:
/Button: J2.3, SW1.1
/D11: J2.4, J3.4
/GND: D1.1 (K), D2.1 (K), D3.1 (K), J1.1, J1.2, J3.6, SW1.2, SW2.2
/ID_LED: J2.5, J3.1, R3.1
/LED: J2.6, J3.3, R1.1
/RST: J1.3, J3.5, SW2.1
/VCC: J2.1, J2.2, J3.2, R2.1
unnamed: D1.2 (A), R1.2
unnamed: D2.2 (A), R2.2
unnamed: D3.2 (A), R3.2

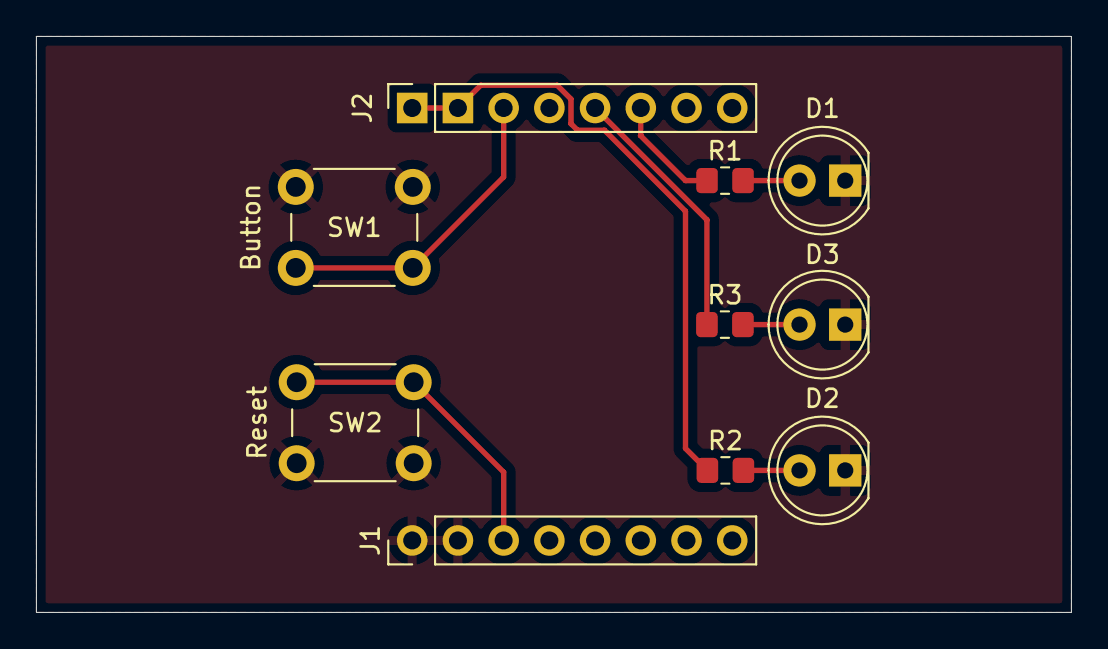
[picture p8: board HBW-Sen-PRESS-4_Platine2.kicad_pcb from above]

Board: 2 copper layers, 57.5 x 32.0 mm, 10 parts (0 on the bottom side), 9 nets.

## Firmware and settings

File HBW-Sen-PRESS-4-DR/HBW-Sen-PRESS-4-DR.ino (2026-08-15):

//*******************************************************************
//
// HBW-Sen-PRESS-4-DR
//
// Homematic Wired Homebrew Hardware
// ATmega328P als Homematic-Device
// Drucksensormodul 4-fach fuer Hutschienenmontage
//
// Basiert auf HBWired von Thorsten Pferdekaemper & Dirk Hoffmann
// (thorsten@pferdekaemper.com, hoffmann@vmd-jena.de)
//
// 2024-04-06 maxx3105
// Creative Commons - http://creativecommons.org/licenses/by-nc-sa/3.0/at/
//
//*******************************************************************
// Aenderungsverlauf:
// v0.01 - Erste Fassung
// v0.02 - doppelte Kanal-Initialisierung behoben
//       - EEPROM-Adressierung korrigiert
//       - OFFSET im Code umgesetzt
//       - Timing der Sendeintervalle korrigiert
// v0.03 - XML auf HMW-Frames umgestellt (INFO_LEVEL '#i', LEVEL_GET '#S'),
//         Sensortyp von interface="config" auf eeprom, OWN_ADDRESS ergaenzt
//       - blockierendes delay() im ADC-Sampling entfernt (SoftwareSerial!)
//       - Sendeergebnis wird ausgewertet (BUS_BUSY -> Wert nicht verwerfen)
//       - Sendelogik vom Messintervall entkoppelt
//       - OFFSET mit Bias 127 statt 0xFF-Sonderfall
//       - feste Kanalzahl 8, count_from_sysinfo entfaellt (Wired kennt es nicht)
// v0.04 - Kanalzahl 8 -> 4 (CRMB2-Gehaeuse fuehrt nur 4 Sensoren heraus)
// v0.05 - Geraet in HBW-Sen-PRESS-4-DR umbenannt
//       - Pinbelegung/EepromPtr in <Name>_config_example.h ausgelagert
//       - Identify-LED ergaenzt (blinkt, solange IDENTIFY_LED gesetzt ist)
//
//*******************************************************************

#define HARDWARE_VERSION 0x01
#define FIRMWARE_VERSION 0x0005
#define HMW_DEVICETYPE 0x50  // Device ID (hbw-sen-press-4-dr.xml auf der CCU installieren)

#define IDENTIFY_LED_INTERVAL 600   // Blinkintervall der Identify-LED in ms

#define NUMBER_OF_CHAN 4   // Drucksensor-Kanaele, belegt A0..A3.
                           // MUSS mit count="4" in der XML uebereinstimmen.
                           /* Die Platine haette 8 ADC-Eingaenge, im CRMB2-Gehaeuse
                            * sind aber nur 4 Sensoren anschliessbar. Eine dynamische
                            * Kanalzahl ueber count_from_sysinfo gibt es im Wired-Zweig
                            * nicht: hs485d kennt das Attribut nicht (binaer belegt,
                            * `strings hs485d` findet weder count_from_sysinfo noch
                            * einen Ersatz; rfd dagegen schon). Ohne count legt die CCU
                            * NULL Kanaele an - am Bus verifiziert. Mehr Kanaele
                            * braeuchten deshalb einen zweiten Geraetetyp mit eigenem
                            * Typ-Byte, wie bei HBW-LC-RGBWW-3/-6. */

// HBWired-Protokoll und Module
#include <Arduino.h>
#include <HBWired.h>
#include "HBWAnalogPRESS.h"
#include <HBW_eeprom.h>

// Pinbelegung, EepromPtr und USE_HARDWARE_SERIAL stehen hier. Bei abweichender
// Hardware die Datei kopieren und die Kopie stattdessen einbinden.
#include "HBW-Sen-PRESS-4-DR_config_example.h"


// Konfigurationsstruktur im EEPROM
// HBWDevice liest sie ab EEPROM-Adresse 0x01 (HBWired.cpp: readConfig)
struct hbw_config {
  uint8_t logging_time;             // 0x01
  uint32_t central_address;         // 0x02-0x05
  uint8_t direct_link_deactivate:1; // 0x06:0
  uint8_t n_identify_led:1;         // 0x06:1  0=Identify-LED an (blinkt), 1=aus
  uint8_t              :6;          // 0x06:2-7

  // Die Kanalkonfiguration beginnt bei 0x07 (XML: address_start="0x07" address_step="8")
  hbw_config_analog_press analogPressConfigs[NUMBER_OF_CHAN];
} hbwconfig;


// EEPROM-Layout gegen die XML absichern. HBWDevice liest die Struktur ab
// EEPROM-Adresse 0x01, struct-Offset 6 entspricht also EEPROM 0x07.
static_assert(sizeof(hbw_config_analog_press) == 8,
              "Kanalstruktur passt nicht zu XML address_step=8");
static_assert(offsetof(hbw_config, analogPressConfigs) == 6,
              "Kanalconfig liegt nicht auf EEPROM 0x07 (XML address_start)");
static_assert(0x01 + sizeof(hbw_config) <= 0x03FC,
              "Config-Bereich kollidiert mit OWN_ADDRESS (E2END-3)");

// Zuordnung der Sensoreingaenge (Reihenfolge = Kanal 1..NUMBER_OF_CHAN),
// steht im Konfig-Header
uint8_t SENSOR_PINS[] = SENSOR_PIN_LIST;

static_assert(sizeof(SENSOR_PINS) >= NUMBER_OF_CHAN,
              "SENSOR_PIN_LIST im Konfig-Header hat weniger Pins als NUMBER_OF_CHAN");

// Geraete- und Kanalobjekte
HBWDevice* device = NULL;
HBWAnalogPRESS* channels[NUMBER_OF_CHAN];


#ifdef IDENTIFY_LED
// Identify-LED, um das Geraet im Verteiler zu finden. Blinkt, solange IDENTIFY_LED
// in der Geraetekonfiguration gesetzt ist. 'n_identify_led' wird invertiert
// gespeichert (siehe XML: boolean_integer invert="true"), damit die LED bei
// blankem EEPROM (0xFF) nach einem Werksreset aus bleibt.
void identifyLedLoop()
{
  static uint32_t lastTime = 0;
  uint32_t now = millis();

  if (hbwconfig.n_identify_led) {
    digitalWrite(IDENTIFY_LED, LOW);
    lastTime = now;
  }
  else if (now - lastTime >= IDENTIFY_LED_INTERVAL) {
    digitalWrite(IDENTIFY_LED, !digitalRead(IDENTIFY_LED));
    lastTime = now;
  }
};
#endif


void setup() {
#ifdef IDENTIFY_LED
  pinMode(IDENTIFY_LED, OUTPUT);
  digitalWrite(IDENTIFY_LED, LOW);
#endif

  // Kanalobjekte anlegen
  for (uint8_t i = 0; i < NUMBER_OF_CHAN; i++) {
    channels[i] = new HBWAnalogPRESS(SENSOR_PINS[i], &hbwconfig.analogPressConfigs[i]);
  }

#ifdef USE_HARDWARE_SERIAL
  // Produktivbetrieb: RS485 ueber die Hardware-UART
  Serial.begin(19200, SERIAL_8E1);

  device = new HBWDevice(HMW_DEVICETYPE, HARDWARE_VERSION, FIRMWARE_VERSION,
                         &Serial, RS485_TXEN, sizeof(hbwconfig), &hbwconfig,
                         NUMBER_OF_CHAN, (HBWChannel**)channels,
                         NULL,  // kein Debug-Stream
                         NULL, NULL);

  device->setConfigPins(BUTTON, LED);
  device->setStatusLEDPins(LED, LED); // Tx/Rx nutzen dieselbe LED wie die Konfiguration

#else
  // Debug-Betrieb: RS485 ueber SoftwareSerial, Debug-Ausgabe ueber die Hardware-UART
  Serial.begin(115200);  // Debug-Ausgabe ueber USB
  rs485.begin(19200);    // RS485 (muss 19200 Baud sein!)

  device = new HBWDevice(HMW_DEVICETYPE, HARDWARE_VERSION, FIRMWARE_VERSION,
                         &rs485, RS485_TXEN, sizeof(hbwconfig), &hbwconfig,
                         NUMBER_OF_CHAN, (HBWChannel**)channels,
                         &Serial,  // Debug-Stream
                         NULL, NULL);

  device->setConfigPins(BUTTON, LED);

  // Startmeldung
  hbwdebug(F("HBW-Sen-PRESS-4-DR v"));
  hbwdebug(FIRMWARE_VERSION);
  hbwdebug(F("\nFree RAM: "));
  hbwdebug(freeRam());
  hbwdebug(F(" bytes\nChannels: "));
  hbwdebug(NUMBER_OF_CHAN);
  hbwdebug(F("\n"));

  // ADC-Rohwerte beim Start ausgeben
  for (uint8_t i = 0; i < NUMBER_OF_CHAN; i++) {
    uint16_t adcValue = analogRead(SENSOR_PINS[i]);

    hbwdebug(F("ADC Ch"));
    hbwdebug(i);
    hbwdebug(F(": "));
    hbwdebug(adcValue);
    hbwdebug(F(" ("));
    hbwdebug((uint16_t)(((uint32_t)adcValue * 5000UL) >> 10));
    hbwdebug(F(" mV)\n"));
  }

  hbwdebug(F("=== Setup complete ===\n"));
#endif
}


void loop() {
  device->loop();

#ifdef IDENTIFY_LED
  identifyLedLoop();
#endif
}

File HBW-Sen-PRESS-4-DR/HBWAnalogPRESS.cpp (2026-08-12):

/*
 * HBWAnalogPRESS.cpp
 *
 * Analogeingang fuer Drucksensoren
 * Unterstuetzt Hydraulik-Drucksensoren 0,5 MPa und 1,2 MPa
 *
 * Basiert auf HBWired von Thorsten Pferdekaemper
 * www.loetmeister.de
 *
 */

#include "HBWAnalogPRESS.h"

HBWAnalogPRESS::HBWAnalogPRESS(uint8_t _pin, hbw_config_analog_press* _config) {
    pin = _pin;
    config = _config;
    lastActionTime = 0;
    nextActionDelay = SAMPLE_INTERVAL;  // Wartezeit bis zur ersten Messung
    adcSum = 0;
    sampleCount = 0;
    currentValue = 0;
    lastSendValue = 0;
    lastSentTime = 0;
}


void HBWAnalogPRESS::afterReadConfig() {
    // Vorgabewerte setzen, wenn das EEPROM leer ist (0xFF)
    if (config->update_interval == 0xFF)   config->update_interval = DEFAULT_UPDATE_INTERVAL;
    if (config->send_delta_value == 0xFF)  config->send_delta_value = 10;   // 0,1 bar
    if (config->send_max_interval == 0xFFFF) config->send_max_interval = 600;  // 10 Minuten
    if (config->send_min_interval == 0xFFFF) config->send_min_interval = 30;
    if (config->offset == 0xFF)            config->offset = OFFSET_BIAS;   // 0,00 bar

    // Sensortyp pruefen: 0=aus, 1=1,2MPa, 2=0,5MPa (faengt auch 0xFF ab)
    if (config->pressure_sensor_type > 2)  config->pressure_sensor_type = 0;
}


/* Standardfunktion - liefert die Laenge des Datenfelds; darin steht der aktuelle Messwert */
uint8_t HBWAnalogPRESS::get(uint8_t* data) {
    // hoeherwertiges Byte zuerst
    *data++ = (currentValue >> 8);
    *data = currentValue & 0xFF;
    return 2;
}


/* Standardfunktion - wird von der Hauptschleife fuer jeden Kanal der Reihe nach aufgerufen */
void HBWAnalogPRESS::loop(HBWDevice* device, uint8_t channel) {
    // Abgeschaltete Kanaele sofort verlassen (Sensortyp = NICHT_BELEGT in der CCU)
    if (config->pressure_sensor_type == 0) {
        currentValue = 0;
        lastSendValue = 0;
        return;
    }

    uint32_t now = millis();

    // === ADC einlesen, eine Messung je Durchlauf (blockiert den Bus nie) ===
    if (now - lastActionTime >= ((uint32_t)nextActionDelay * 1000)) {
        lastActionTime = now;
        nextActionDelay = SAMPLE_INTERVAL;

        adcSum += analogRead(pin);
        sampleCount++;

        if (sampleCount >= MAX_SAMPLES) {
            uint16_t avgADC = adcSum / MAX_SAMPLES;
            adcSum = 0;
            sampleCount = 0;
            nextActionDelay = config->update_interval;  // Pause bis zur naechsten Messreihe

            // === ADC-Wert in Millivolt umrechnen (ratiometrisch, VCC-Referenz) ===
            uint32_t voltage = ((uint32_t)avgADC * 5000UL) >> 10;

            // === Druck berechnen: 0,5 V = 0 bar, 4,5 V = Endwert ===
            if (voltage <= SENSOR_OFFSET_MV) {
                currentValue = 0;
            }
            else {
                // Endwert in 0,01 bar
                uint16_t maxBar = (config->pressure_sensor_type == 1) ? 1200 : 500;
                currentValue = (uint16_t)(((voltage - SENSOR_OFFSET_MV) * maxBar) / SENSOR_RANGE_MV);
            }

            // === Kalibrier-Offset anwenden (mit Bias 127 gespeichert) ===
            int32_t corrected = (int32_t)currentValue + ((int16_t)config->offset - OFFSET_BIAS);
            if (corrected < 0)            currentValue = 0;
            else if (corrected > 0xFFFF)  currentValue = 0xFFFF;
            else                          currentValue = (uint16_t)corrected;

#ifdef DEBUG_OUTPUT
            hbwdebug(F("press-ch:"));  hbwdebug(channel);
            hbwdebug(F(" adc:"));  hbwdebug(avgADC);
            hbwdebug(F(" measured:"));  hbwdebug(currentValue);  hbwdebug(F("\n"));
#endif
        }
    }

    // === Sendelogik - unabhaengig vom Messzyklus ===
    // vor Ablauf des Mindestintervalls nicht senden
    if (config->send_min_interval && now - lastSentTime < (uint32_t)config->send_min_interval * 1000)
        return;

    uint16_t delta = (currentValue > lastSendValue) ? (currentValue - lastSendValue)
                                                    : (lastSendValue - currentValue);

    if ((config->send_max_interval && now - lastSentTime >= (uint32_t)config->send_max_interval * 1000) ||
        (config->send_delta_value && delta >= config->send_delta_value)) {

        uint8_t data[2];
        get(data);
        if (device->sendInfoMessage(channel, sizeof(data), data) != HBWDevice::BUS_BUSY) {
            lastSendValue = currentValue;   // nur bei Erfolg als gesendet vermerken
        }
        lastSentTime = now;   // bei Fehlschlag greift send_max_interval oder das naechste Delta

#ifdef DEBUG_OUTPUT
        hbwdebug(F("press-ch: "));  hbwdebug(channel);
        hbwdebug(F(" sent: "));  hbwdebug(lastSendValue);
        lastSendValue == currentValue ? hbwdebug(F(" SUCCESS!\n")) : hbwdebug(F(" FAILED!\n"));
#endif
    }
}

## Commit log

2026-08-11 Firmware v0.04: Sketch, CCU-XML und Doku ergaenzen
    Bisher lag hier nur die Hardware (KiCad Platine1/Platine2). Dazu jetzt die
    lauffaehige Firmware auf Basis von HBWired.
    4 Kanaele (A0..A3) - die Platine fuehrt 8 ADC-Eingaenge, das CRMB2-Gehaeuse
    aber nur 4 Sensoranschluesse heraus. NUMBER_OF_CHAN und count in der XML
    muessen uebereinstimmen; eine dynamische Kanalzahl ueber count_from_sysinfo
    gibt es im Wired-Zweig nicht (hs485d kennt das Attribut nicht - im Binary
    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
2026-08-12 Doku und Code-Kommentare durchgaengig auf Deutsch
    Das README stammte noch aus dem v0.02-Stand und war englisch, waehrend
    BUGFIXES.md und CLAUDE.md deutsch sind - die Sprachen liefen im Repo
    auseinander. Jetzt einheitlich deutsch:
    - README komplett uebersetzt und dabei zwei Fehler korrigiert: die
    Platinen-Ordner sind nicht "PCB revision 1/2" (Platine2 ist eine eigene
    kleine Platine), und das Beispiel der Debug-Ausgabe zeigte noch v2
    - Kommentare in HBWAnalogPRESS.h/.cpp und im Sketch uebersetzt
    - Ergaenzt: Hinweis auf die EESAVE-Fuse (ISP-Flash loescht sonst das EEPROM
    samt Busadresse) und die Rechnung fuer die Messrate
    ((MAX_SAMPLES-1) * SAMPLE_INTERVAL + UPDATE_INTERVAL, per Vorgab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
    [HBW-Sen-PRESS-DR.ino, HBWAnalogPRESS.cpp]
2026-08-12 Revise README for clarity on sensor channels
    Updated the README to clarify sensor channel usage and configuration details.
2026-08-15 v0.05: Umbenennung auf HBW-Sen-PRESS-4-DR, Konfig-Header, Identify-LED
    Umbenennung
    - Sketch-Ordner, .ino, XML-Datei und <type id=...> heissen jetzt
    HBW-Sen-PRESS-4-DR. Das Typ-Byte bleibt 0x50.
    - Wegen des Namenswechsels muss das Geraet in der CCU geloescht und neu
    angelernt werden.
    Konfig-Header (Struktur wie beim HBW-1W-T10)
    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
2026-08-16 Update button and LED pin definitions
2026-08-16 Update pin assignment for factory reset button

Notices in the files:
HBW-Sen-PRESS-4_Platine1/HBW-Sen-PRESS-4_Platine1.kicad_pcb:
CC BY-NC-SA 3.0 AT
